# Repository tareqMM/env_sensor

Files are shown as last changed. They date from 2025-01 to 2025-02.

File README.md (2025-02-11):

# 🌡️ Environmental Sensor - Zigbee & BLE IoT Device

## 📌 Overview

A **low-power, wireless temperature and humidity sensor** designed for seamless integration with **Zigbee networks and Home Assistant**. If you need a **smart way to monitor indoor conditions** and receive timely **reminders to improve air quality**, this customizable IoT sensor is the perfect solution.

Instead of purchasing a commercial device with limited customization, you can **build, modify, and tailor** this ultra-low-power sensor to suit your specific needs. In this project, I share the **design, source code, and hardware details**, giving you complete flexibility and control. 🚀  

---

## ⚡ Key Features

✅ **Ultra-low power consumption** – Uses only **20µA on average**, powered by a **CR2032 coin cell** for long-lasting performance.  
✅ **Reliable wireless communication** – Built around the **nRF52833** microcontroller with a **2.45 GHz PCB monopole antenna**, supporting both **BLE and Zigbee**.  
✅ **High-precision sensing** – Incorporates the **Sensirion SHT40 sensor** with an accuracy of **±0.2°C** and **±1.8% RH**.  
✅ **Two buttons** (reset and user-defined functions, currently set for factory reset).  
✅ **Status LED** for easy monitoring.  
✅ **Pin header** for debugging or external peripherals.  
✅ **Tag-Connect programming header** for effortless firmware updates.  

| Board top side | Board bottom side |
|---|---|
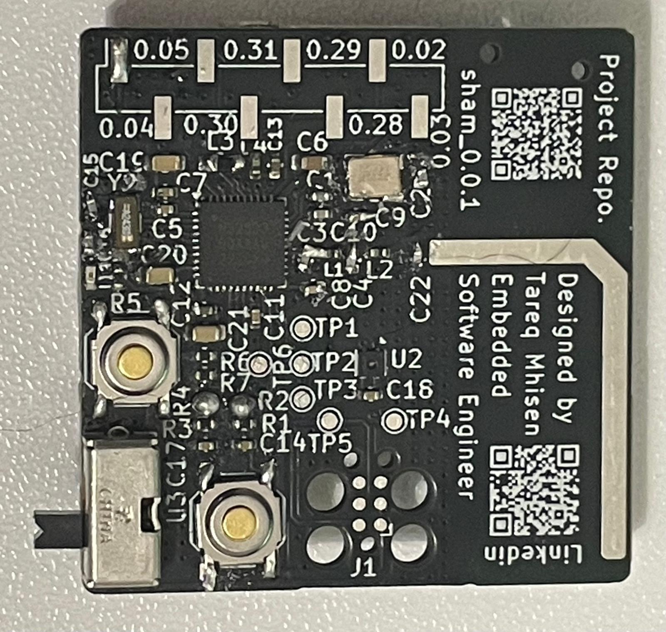
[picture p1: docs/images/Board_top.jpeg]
Board top side
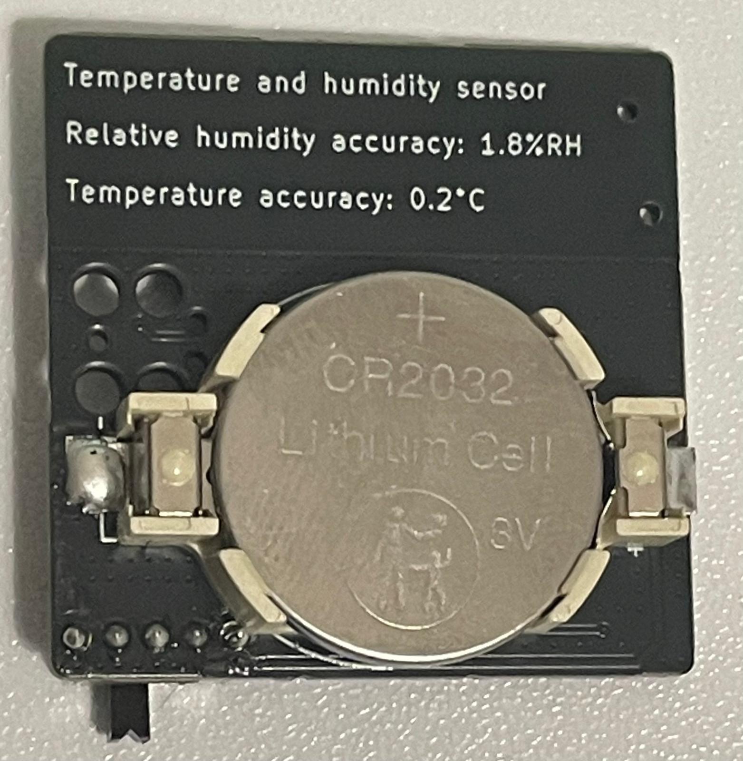
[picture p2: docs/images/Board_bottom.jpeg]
Board bottom side
|  |  |

---

## 🔧 Firmware & Integration

### 📡 Zigbee Mode  

- Functions as a **Zigbee sleepy end device**, ensuring low power consumption and seamless integration into existing Zigbee networks and **Home Assistant**.  
- Built on **Zephyr RTOS**, providing a modular and expandable architecture.  
- Supports configurable **device ID, vendor settings, and measurement intervals (TBD)**.  
- Designed for easy expansion, allowing additional sensors (e.g., pressure, gas) with minimal code modifications.  

| Adding to Home Assistant | Overview in Home Assistant |
|---|---|
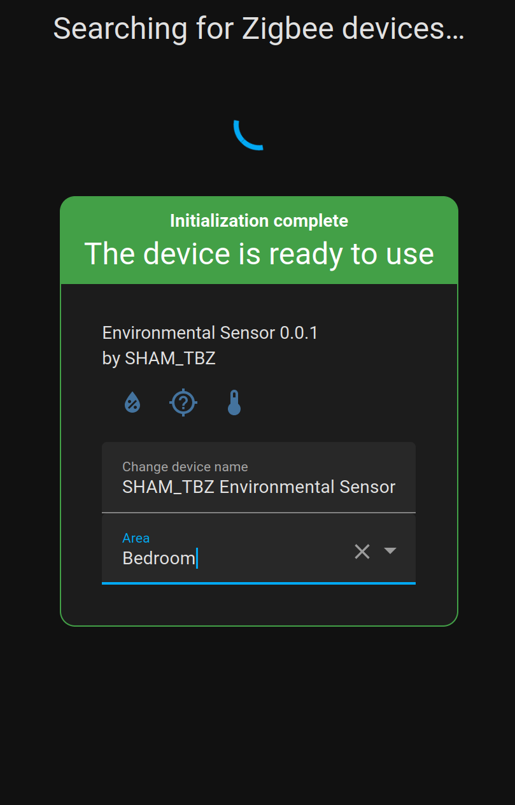
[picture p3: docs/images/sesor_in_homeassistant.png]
Sensor Integration
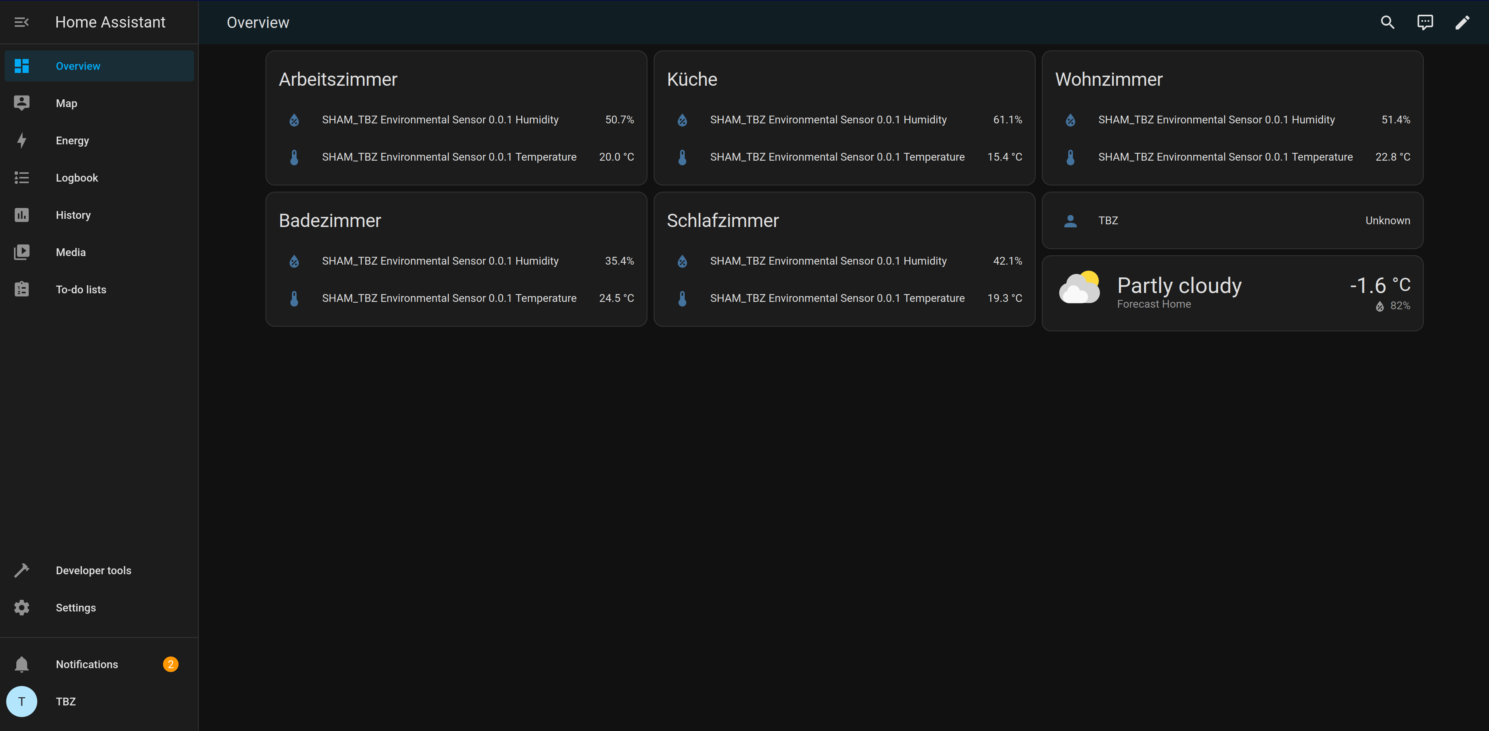
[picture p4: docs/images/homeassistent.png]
Ready to Use
|  |  |

### 📶 BLE Mode *(Upcoming Feature)*  

For those without a Zigbee network, a **BLE beacon firmware** will enable the device to act as a **Bluetooth Low Energy temperature and humidity sensor**, transmitting real-time data directly to a smartphone.

---

## 📢 Contribute & Customize

This project is designed for flexibilit whether you want to tweak the firmware, modify the hardware, or add new features, you are encouraged to contribute, suggest improvements, or fork the project to fit your specific needs.

Let's build smarter, more personalized environmental monitoring together! 🌍🔧

## Getting started

Before getting started, make sure you have a proper nRF Connect SDK development environment.
Follow the official
[Getting started guide](https://developer.nordicsemi.com/nRF_Connect_SDK/doc/latest/nrf/getting_started.html).

### Initialization

```shell
# Prepare workspace and virtual env
mkdir ws
python -m venv --copies ws/.venv
. ws/.venv/bin/activate
pip install west

# Initialize workspace
west init -m git@github.com:TAREQ-TBZ/env_sensor.git --mr main ws
cd ws
west update

# Install additional requirements
pip install -r zephyr/scripts/requirements.txt
pip install -r nrf/scripts/requirements.txt
pip install -r bootloader/mcuboot/scripts/requirements.txt
```

### Building and running

To build the main application, run the following command:

```shell
west build --sysbuild -b <YOURBOARD> application/app
```

To build the application for the sham_nrf52833 board

```shell
west build -b sham_nrf52833 application/app
```

To flash the firmware:

```shell
west flash
```

## Building with vscode

Add the board folder and application to NRF Connect in your .vscode/settings.json

```json
{
    "nrf-connect.applications": [
        "${workspaceFolder}/application/app"
    ],
    "nrf-connect.boardRoots": [
        "${workspaceFolder}/application/"
    ]
}
```

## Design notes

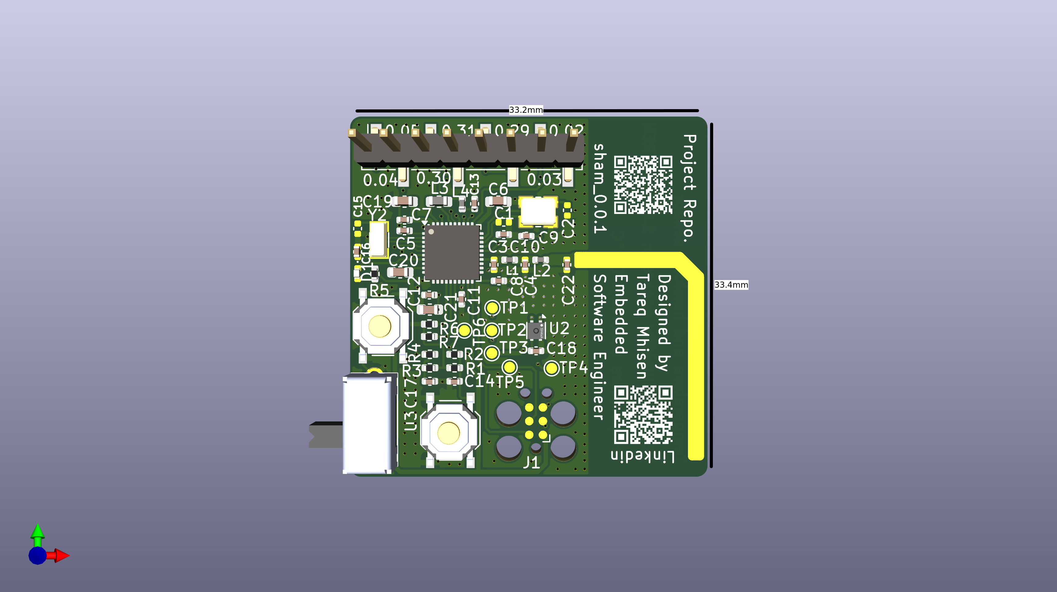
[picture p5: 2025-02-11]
docs/images/Board_3D.png

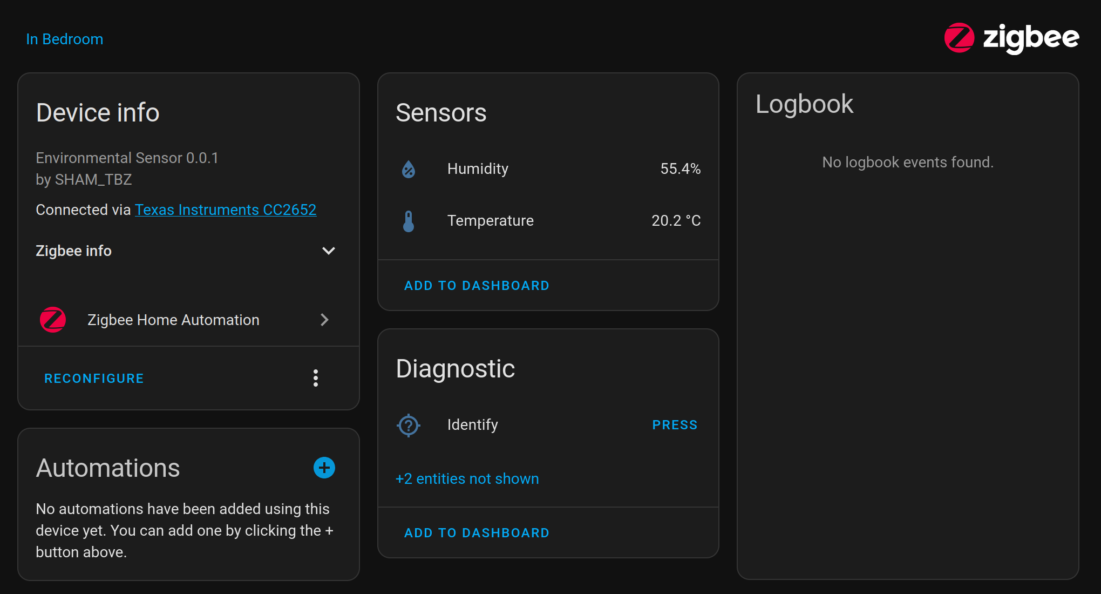
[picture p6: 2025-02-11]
docs/images/ready_to_use_sensor.png

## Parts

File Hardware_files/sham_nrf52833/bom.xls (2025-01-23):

Comment | Designator | Footprint | JLCPCB Part #
LQG15HS15NJ02D | L4 | Inductor_SMD:L_0402_1005Metric | C86059
1.0uF | C12,C13 | Capacitor_SMD:C_0402_1005Metric | C52923
SHT4x | U2 | Sensor_Humidity:Sensirion_DFN-4_1.5x1.5mm_P0.8mm_SHT4x_NoCentralPad | C2848306
nRF52833_QDxx | U1 | Package_DFN_QFN:QFN-40-1EP_5x5mm_P0.4mm_EP3.6x3.6mm | C2895249
LQG15HS2N2B02D | L2 | Inductor_SMD:L_0402_1005Metric | C162540
47uF | C19,C20,C21 | Capacitor_SMD:C_0603_1608Metric | C140782
LQG15HS4N7B02D | L1 | Inductor_SMD:L_0402_1005Metric | C162543
47nF | C9 | Capacitor_SMD:C_0402_1005Metric | C82219
1M | R1,R2,R3,R4 | Resistor_SMD:R_0402_1005Metric | C26083
4.7uF | C6 | Capacitor_SMD:C_0603_1608Metric | C19666
100pF | C10 | Capacitor_SMD:C_0402_1005Metric | C1546
100nF | C5,C7,C11,C14,C17,C18 | Capacitor_SMD:C_0402_1005Metric | C1525
10k | R6,R7 | Resistor_SMD:R_0402_1005Metric | C25744
 |  |  | MOUSER Part #
560ohms | R5 | Resistor_SMD:R_0402_1005Metric | XGNF5600Y
32MHz | Y1 | kicad_libs:OSCCC320X250X60N | CX3225SB32000D0FPLCC
32.768kHz | Y2 | Crystal:Crystal_SMD_3215-2Pin_3.2x1.5mm | FC-135 32.7680KA-AC0
SLIDE SWITCH SPDT Right Angle | U3 | kicad_libs:1825232-1 | 1825232-1
1.0pF,NPO,5% | C3 | Capacitor_SMD:C_0402_1005Metric | GRM0225C1C1R0WA03L
820pF | C8 | Capacitor_SMD:C_0402_1005Metric | 04023C821KAT4A
12pF,NPO,2% | C1,C2,C15,C16 | Capacitor_SMD:C_0402_1005Metric | CQ0100GRNPO8BN120
10uH 5% | L3 | Inductor_SMD:L_0603_1608Metric | 78F100J-RC
APHHS1005LSECK/J3-PF | D1 | LED_SMD:LED_0402_1005Metric | APHHS1005LSECK
Push button | SW1,SW2 | Button_Switch_SMD:SW_Push_1P1T_XKB_TS-1187A | PTS526 SKG15J SMTR2 LFS
1.2pF,NPO,5% | C4,C22 | Capacitor_SMD:C_0402_1005Metric | GJM0225C1C1R2WB01L

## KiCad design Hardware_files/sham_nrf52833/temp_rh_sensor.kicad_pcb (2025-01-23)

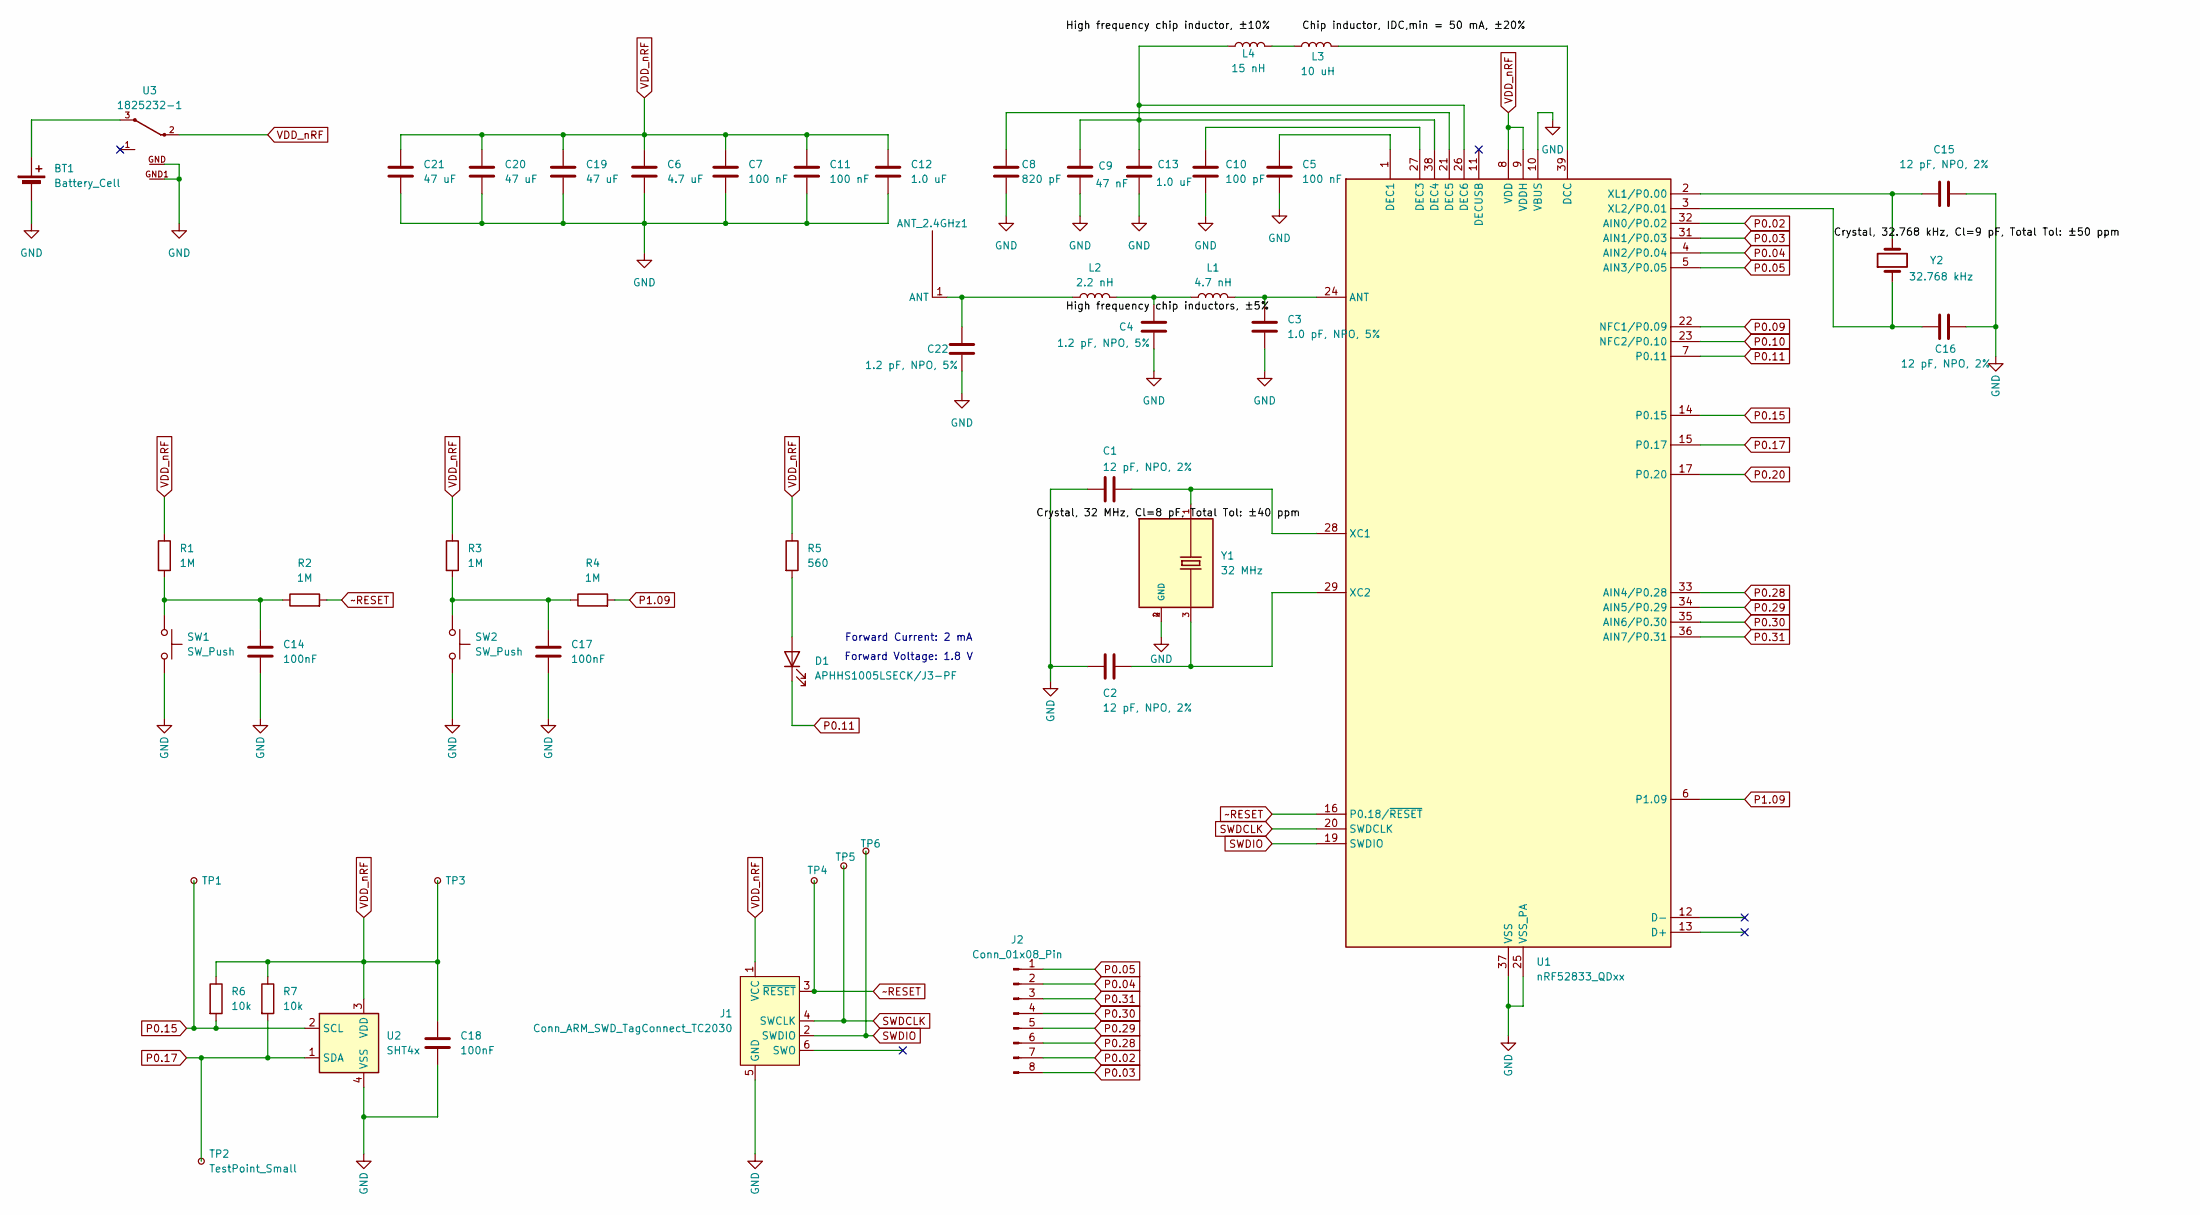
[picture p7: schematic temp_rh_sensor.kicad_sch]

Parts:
ANT_2.4GHz1: antenna_2_4GHz
BT1: Battery_Cell; RENATA_SMTU2032-1
C1, C2, C15, C16: 12 pF, NPO, 2%; C_0402_1005Metric
C3: 1.0 pF, NPO, 5%; C_0402_1005Metric
C4, C22: 1.2 pF, NPO, 5%; C_0402_1005Metric
C5, C7, C11: 100 nF; C_0402_1005Metric
C6: 4.7 uF; C_0603_1608Metric
C8: 820 pF; C_0402_1005Metric
C9: 47 nF; C_0402_1005Metric
C10: 100 pF; C_0402_1005Metric
C12, C13: 1.0 uF; C_0402_1005Metric
C14, C17, C18: 100nF; C_0402_1005Metric
C19, C20, C21: 47 uF; C_0603_1608Metric
D1: APHHS1005LSECK/J3-PF; LED_0402_1005Metric
J1: Conn_ARM_SWD_TagConnect_TC2030; Tag-Connect_TC2030-IDC-FP_2x03_P1.27mm_Vertical
J2: Conn_01x08_Pin; PinHeader_1x08_P2.54mm_Vertical_SMD_Pin1Right
L1: 4.7 nH; L_0402_1005Metric
L2: 2.2 nH; L_0402_1005Metric
L3: 10 uH; L_0603_1608Metric
L4: 15 nH; L_0402_1005Metric
R1, R2, R3, R4: 1M; R_0402_1005Metric
R5: 560; R_0402_1005Metric
R6, R7: 10k; R_0402_1005Metric
SW1, SW2: SW_Push; SW_Push_1P1T_XKB_TS-1187A
TP1, TP2, TP3, TP4, TP5, TP6: TestPoint_Small; TestPoint_Pad_D1.0mm
U1: nRF52833_QDxx; QFN-40-1EP_5x5mm_P0.4mm_EP3.6x3.6mm
U2: SHT4x; Sensirion_DFN-4_1.5x1.5mm_P0.8mm_SHT4x_NoCentralPad
U3: 1825232-1
Y1: 32 MHz; OSCCC320X250X60N; PARTREV N/A
Y2: 32.768 kHz; Crystal_SMD_3215-2Pin_3.2x1.5mm

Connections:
/Crystal, 32.768 kHz, Cl=9 pF, Total Tol: ±50 ppm: C16.1, U1.3 (XL2/P0.01), Y2.1
GND: BT1.2 (-), C1.2, C2.2, C3.2, C4.2, C5.2, C6.2, C7.2, C8.2, C9.2, C10.2, C11.2, C12.2, C13.2, C14.2, C15.2, C16.2, C17.2, C18.2, C19.2, C20.2, C21.2, C22.2, J1.5 (GND), SW1.2, SW2.2, U1.10 (VBUS), U1.25 (VSS_PA), U1.37 (VSS), U1.41 (VSS), U2.4 (VSS), U3.GND, U3.GND1, Y1.2 (GND), Y1.4 (GND)
unnamed: ANT_2.4GHz1.1 (ANT), C22.1, L2.1
unnamed: BT1.1 (+), U3.3
unnamed: C4.1, L1.1, L2.2
unnamed: C14.1, R1.2, R2.1, SW1.1
unnamed: C17.1, R3.2, R4.1, SW2.1
unnamed: D1.2 (A), R5.2
unnamed: L3.1, L4.2
unnamed: C3.1, L1.2, U1.24 (ANT)
unnamed: L3.2, U1.39 (DCC)
unnamed: C5.1, U1.1 (DEC1)
unnamed: C10.1, U1.27 (DEC3)
unnamed: C9.1, C13.1, L4.1, U1.26 (DEC6), U1.38 (DEC4)
unnamed: C8.1, U1.21 (DEC5)
unnamed: C1.1, U1.28 (XC1), Y1.1
unnamed: C2.1, U1.29 (XC2), Y1.3
unnamed: C15.1, U1.2 (XL1/P0.00), Y2.2
P0.02: J2.7, U1.32 (AIN0/P0.02)
P0.03: J2.8, U1.31 (AIN1/P0.03)
P0.04: J2.2, U1.4 (AIN2/P0.04)
P0.05: J2.1, U1.5 (AIN3/P0.05)
P0.09: U1.22 (NFC1/P0.09)
P0.10: U1.23 (NFC2/P0.10)
P0.11: D1.1 (K), U1.7 (P0.11)
P0.15: R6.2, TP1.1, U1.14 (P0.15), U2.2 (SCL)
P0.17: R7.2, TP2.1, U1.15 (P0.17), U2.1 (SDA)
P0.20: U1.17 (P0.20)
P0.28: J2.6, U1.33 (AIN4/P0.28)
P0.29: J2.5, U1.34 (AIN5/P0.29)
P0.30: J2.4, U1.35 (AIN6/P0.30)
P0.31: J2.3, U1.36 (AIN7/P0.31)
P1.09: R4.2, U1.6 (P1.09)
SWDCLK: J1.4 (SWCLK), TP5.1, U1.20 (SWDCLK)
SWDIO: J1.2 (SWDIO), TP6.1, U1.19 (SWDIO)
VDD_nRF: C6.1, C7.1, C11.1, C12.1, C18.1, C19.1, C20.1, C21.1, J1.1 (VCC), R1.1, R3.1, R5.1, R6.1, R7.1, TP3.1, U1.8 (VDD), U1.9 (VDDH), U1.18 (VDD), U1.30 (VDD), U1.40 (VDD), U2.3 (VDD), U3.2
~RESET: J1.3 (~RESET), R2.2, TP4.1, U1.16 (P0.18/~RESET)

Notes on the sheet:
Forward Voltage: 1.8 V
Forward Current: 2 mA

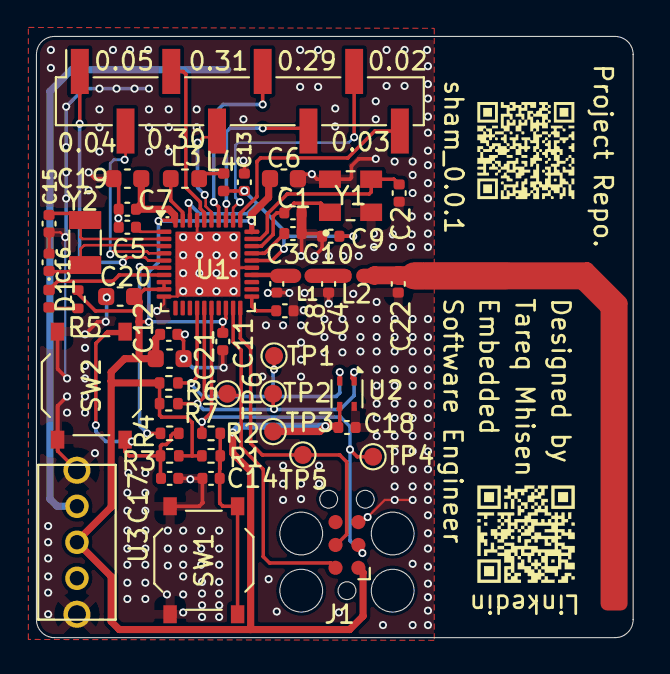
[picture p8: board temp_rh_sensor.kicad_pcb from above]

Board: 2 copper layers, 33.2 x 33.4 mm, 51 parts (1 on the bottom side), 34 nets.

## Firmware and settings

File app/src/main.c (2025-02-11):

/*
 * Copyright (c) 2024 Tareq Mhisen
 *
 * SPDX-License-Identifier: Apache-2.0
 */

#include <zephyr/logging/log.h>
#include <zephyr/sys/reboot.h>

#include "events_svc.h"
#include "humidity_temperature_svc.h"
#include "user_interface.h"
#include "zigbee_svc.h"

LOG_MODULE_REGISTER(main, LOG_LEVEL_INF);

#define MEASUREMENT_PERIOD_MSEC      (1000 * CONFIG_MEASURING_PERIOD_SECONDS)
#define FIRST_MEASUREMENT_DELAY_MSEC (1000 * CONFIG_FIRST_MEASUREMENT_DELAY_SECONDS)

static void measuring_work_handler(struct k_work *_work)
{
	int ret;
	struct k_work_delayable *work = k_work_delayable_from_work(_work);

	ret = humidity_temperature_svc_trigger_measurement();
	if (ret != 0) {
		LOG_ERR("Failed to trigger humidity and temperature measurement: %d", ret);
	} else {
		ret = zigbee_svc_schedule_fn(
			ZIGBEE_UPDATE_TEMPERATURE_ATTRIBUTE,
			humidity_temperature_svc_get_temperature() *
				ZCL_TEMPERATURE_MEASUREMENT_MEASURED_VALUE_MULTIPLIER);
		if (ret != 0) {
			LOG_ERR("Failed to update ZCL temperature attribute!");
		}

		ret = zigbee_svc_schedule_fn(
			ZIGBEE_UPDATE_HUMIDITY_ATTRIBUTE,
			humidity_temperature_svc_get_humidity() *
				ZCL_HUMIDITY_MEASUREMENT_MEASURED_VALUE_MULTIPLIER);
		if (ret != 0) {
			LOG_ERR("Failed to update ZCL humidity attribute!");
		}
	}

	k_work_reschedule(work, K_MSEC(MEASUREMENT_PERIOD_MSEC));
}
K_WORK_DELAYABLE_DEFINE(measuring_work, measuring_work_handler);

static void btn_callback(enum button_evt evt)
{
	int ret;
	switch (evt) {
	case BUTTON_EVT_PRESSED_1_SEC:
		ret = zigbee_svc_schedule_fn(ZIGBEE_START_JOINING, 0);
		if (ret != 0) {
			LOG_ERR("Failed to start joining procedure!");
		}

		break;

	case BUTTON_EVT_PRESSED_3_SEC:
		break;

	case BUTTON_EVT_PRESSED_10_SEC:
		ret = zigbee_svc_schedule_fn(ZIGBEE_WIPE_DATA, 0);
		if (ret != 0) {
			LOG_ERR("Failed to wipe zigbee data!");
		}
		break;

	default:
		break;
	}
}

int main(void)
{
	int ret;

	LOG_INF("Starting up .. .. ..");

	ret = humidity_temperature_svc_init();
	if (ret != 0) {
		LOG_ERR("Failed to initialize humidity and temperature service!");
	}

	if (ui_gpio_init() != 0) {
		LOG_ERR("Failed to initialize GPIOs!");
	}

	ui_register_button_callback(btn_callback);

	zigbee_svc_init();

	zigbee_svc_start();

	while (true) {
		struct event evt;

		/* Wait for the next event */
		ret = events_svc_get_event(&evt);
		if (ret != 0) {
			LOG_WRN("Unable to get event. Err: %d", ret);
			continue;
		}

		LOG_INF("Event: %s", events_svc_type_to_text(evt.type));

		switch (evt.type) {
		case EVENT_NETWORK_CONNECTED:
			k_work_reschedule(&measuring_work,
					  K_MSEC(CONFIG_FIRST_MEASUREMENT_DELAY_SECONDS));
			break;

		case EVENT_NETWORK_NOT_CONNECTED:
			struct k_work_sync sync;
			k_work_cancel_delayable_sync(&measuring_work, &sync);
			break;

		case EVENT_ZIGBEE_DATA_WIPED:
			/* Trigger software reboot after performing factory reset */
			LOG_WRN("Rebooting device after performing factory reset . . .");
			k_msleep(1000);
			(void)ui_set_status_led_off();
			sys_reboot(SYS_REBOOT_COLD);
			break;

		default:
			break;
		}
	}
	return 0;
}

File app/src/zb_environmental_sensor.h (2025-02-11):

/*
 * Copyright (c) 2022 Nordic Semiconductor ASA
 * Copyright (c) 2024 Tareq Mhisen
 *
 * SPDX-License-Identifier: LicenseRef-Nordic-5-Clause
 * SPDX-License-Identifier: Apache-2.0
 */

#ifndef APP_ENVIRONMENTAL_SENSOR_H
#define APP_ENVIRONMENTAL_SENSOR_H

#include <zcl/zb_zcl_temp_measurement_addons.h>
#include <zcl/zb_zcl_basic_addons.h>

/* Zigbee Cluster Library 4.4.2.2.1.1: MeasuredValue = 100x temperature in degrees Celsius */
#define ZCL_TEMPERATURE_MEASUREMENT_MEASURED_VALUE_MULTIPLIER 100
/* Zigbee Cluster Library 4.7.2.1.1: MeasuredValue = 100x water content in % */
#define ZCL_HUMIDITY_MEASUREMENT_MEASURED_VALUE_MULTIPLIER    100

/* Measurements ranges scaled for attribute values */
#define ENVIRONMENTAL_SENSOR_ATTR_TEMP_MIN                                                         \
	(SENSOR_TEMP_CELSIUS_MIN * ZCL_TEMPERATURE_MEASUREMENT_MEASURED_VALUE_MULTIPLIER)
#define ENVIRONMENTAL_SENSOR_ATTR_TEMP_MAX                                                         \
	(SENSOR_TEMP_CELSIUS_MAX * ZCL_TEMPERATURE_MEASUREMENT_MEASURED_VALUE_MULTIPLIER)
#define ENVIRONMENTAL_SENSOR_ATTR_TEMP_TOLERANCE                                                   \
	(SENSOR_TEMP_CELSIUS_TOLERANCE * ZCL_TEMPERATURE_MEASUREMENT_MEASURED_VALUE_MULTIPLIER)

#define ENVIRONMENTAL_SENSOR_ATTR_HUMIDITY_MIN                                                     \
	(SENSOR_HUMIDITY_PERCENT_MIN * ZCL_HUMIDITY_MEASUREMENT_MEASURED_VALUE_MULTIPLIER)
#define ENVIRONMENTAL_SENSOR_ATTR_HUMIDITY_MAX                                                     \
	(SENSOR_HUMIDITY_PERCENT_MAX * ZCL_HUMIDITY_MEASUREMENT_MEASURED_VALUE_MULTIPLIER)

/* Number chosen for the single endpoint provided by weather station */
#define ENVIRONMENTAL_SENSOR_ENDPOINT_NB 42

/* Temperature sensor device version */
#define ZB_HA_DEVICE_VER_TEMPERATURE_SENSOR       0
/* Basic, temperature, humidity */
#define ZB_HA_ENVIRONMENTAL_SENSOR_IN_CLUSTER_NUM 3

#define ZB_HA_ENVIRONMENTAL_SENSOR_OUT_CLUSTER_NUM 0

/* Temperature, humidity */
#define ZB_HA_ENVIRONMENTAL_SENSOR_REPORT_ATTR_COUNT 2

/** @brief Declare cluster list for environmental sensor device
    @param cluster_list_name - cluster list variable name
    @param basic_attr_list - attribute list for Basic cluster
    @param temperature_measurement_attr_list - attribute list for temperature measurement cluster
    @param humidity_measurement_attr_list - attribute list for humidity measurement cluster
 */
#define ZB_HA_DECLARE_ENVIRONMENTAL_SENSOR_CLUSTER_LIST(cluster_list_name, basic_attr_list,        \
							temperature_measurement_attr_list,         \
							humidity_measurement_attr_list)            \
	zb_zcl_cluster_desc_t cluster_list_name[] = {                                              \
		ZB_ZCL_CLUSTER_DESC(ZB_ZCL_CLUSTER_ID_BASIC,                                       \
				    ZB_ZCL_ARRAY_SIZE(basic_attr_list, zb_zcl_attr_t),             \
				    (basic_attr_list), ZB_ZCL_CLUSTER_SERVER_ROLE,                 \
				    ZB_ZCL_MANUF_CODE_INVALID),                                    \
		ZB_ZCL_CLUSTER_DESC(                                                               \
			ZB_ZCL_CLUSTER_ID_TEMP_MEASUREMENT,                                        \
			ZB_ZCL_ARRAY_SIZE(temperature_measurement_attr_list, zb_zcl_attr_t),       \
			(temperature_measurement_attr_list), ZB_ZCL_CLUSTER_SERVER_ROLE,           \
			ZB_ZCL_MANUF_CODE_INVALID),                                                \
		ZB_ZCL_CLUSTER_DESC(                                                               \
			ZB_ZCL_CLUSTER_ID_REL_HUMIDITY_MEASUREMENT,                                \
			ZB_ZCL_ARRAY_SIZE(humidity_measurement_attr_list, zb_zcl_attr_t),          \
			(humidity_measurement_attr_list), ZB_ZCL_CLUSTER_SERVER_ROLE,              \
			ZB_ZCL_MANUF_CODE_INVALID),                                                \
	}

#define ZB_ZCL_DECLARE_ENVIRONMENTAL_SENSOR_DESC(ep_name, ep_id, in_clust_num, out_clust_num)      \
	ZB_DECLARE_SIMPLE_DESC(in_clust_num, out_clust_num);                                       \
	ZB_AF_SIMPLE_DESC_TYPE(in_clust_num, out_clust_num)                                        \
	simple_desc_##ep_name = {ep_id,                                                            \
				 ZB_AF_HA_PROFILE_ID,                                              \
				 ZB_HA_TEMPERATURE_SENSOR_DEVICE_ID,                               \
				 ZB_HA_DEVICE_VER_TEMPERATURE_SENSOR,                              \
				 0,                                                                \
				 in_clust_num,                                                     \
				 out_clust_num,                                                    \
				 {                                                                 \
					 ZB_ZCL_CLUSTER_ID_BASIC,                                  \
					 ZB_ZCL_CLUSTER_ID_TEMP_MEASUREMENT,                       \
					 ZB_ZCL_CLUSTER_ID_REL_HUMIDITY_MEASUREMENT,               \
				 }}

#define ZB_HA_DECLARE_ENVIRONMENTAL_SENSOR_EP(ep_name, ep_id, cluster_list)                        \
	ZB_ZCL_DECLARE_ENVIRONMENTAL_SENSOR_DESC(ep_name, ep_id,                                   \
						 ZB_HA_ENVIRONMENTAL_SENSOR_IN_CLUSTER_NUM,        \
						 ZB_HA_ENVIRONMENTAL_SENSOR_OUT_CLUSTER_NUM);      \
	ZBOSS_DEVICE_DECLARE_REPORTING_CTX(reporting_info##ep_name,                                \
					   ZB_HA_ENVIRONMENTAL_SENSOR_REPORT_ATTR_COUNT);          \
	ZB_AF_DECLARE_ENDPOINT_DESC(                                                               \
		ep_name, ep_id, ZB_AF_HA_PROFILE_ID, 0, NULL,                                      \
		ZB_ZCL_ARRAY_SIZE(cluster_list, zb_zcl_cluster_desc_t), cluster_list,              \
		(zb_af_simple_desc_1_1_t *)&simple_desc_##ep_name,                                 \
		ZB_HA_ENVIRONMENTAL_SENSOR_REPORT_ATTR_COUNT, reporting_info##ep_name, 0, NULL)

/**@brief Temperature Measurement cluster attributes according to ZCL Spec 4.7.2.2.1. */
struct zb_zcl_humidity_measurement_attrs_t {
	zb_uint16_t measure_value;
	zb_uint16_t min_measure_value;
	zb_uint16_t max_measure_value;
};

struct zb_device_ctx {
	zb_zcl_basic_attrs_ext_t basic_attr;
	zb_zcl_temp_measurement_attrs_t temp_attrs;
	struct zb_zcl_humidity_measurement_attrs_t humidity_attrs;
};

#endif /* APP_ENVIRONMENTAL_SENSOR_H */

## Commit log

2025-01-23 boards: add sham_nrf52833 board
    sham_nrf52833 is the main board used for this project.
    [bom.xls, temp_rh_sensor.kicad_pcb, temp_rh_sensor.kicad_sch]
2025-02-11 app: add user interface module
    This commit introduces the user interface service, which handles LED
    indicators and button inputs.
2025-02-11 app: add humidity & temperature service
    This change introduces the humidity and temperature sensor service,
    responsible for interfacing with the sensor. The service provides functions
    to read and process environmental data, which can then be transmitted over
    Zigbee.
2025-02-11 app: add zigbee cluster definitions for env. sensor
2025-02-11 app: add zigbee service to transmit the env. data
    This commit adds the Zigbee communication service, allowing the device
    to function as a Zigbee sleepy end-device and wirelessly transmmit
    humidity and temperature data over Zigbee network to the coordinator.
